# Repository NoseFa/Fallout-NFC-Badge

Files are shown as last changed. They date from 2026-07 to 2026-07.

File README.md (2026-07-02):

# Fallout NFC badge

An NFC badge made for Hack Club Fallout. This project was done on the first full day of Hack Club Fallout as a PCB sprint project. We had around like 7-8h from start to finish. The badge was made to fit the holders / landyards given to us at the event. The badge includes an nfc tag and a whitescreen with a QR code to the fallout home page and a code to my github profile on the back side. I will probably program the nfc tag to forward to the photo site so I can quickly give people access to it. This was also one of my first KiCad projects with PCBA components so it's pretty bare bones and simple. 

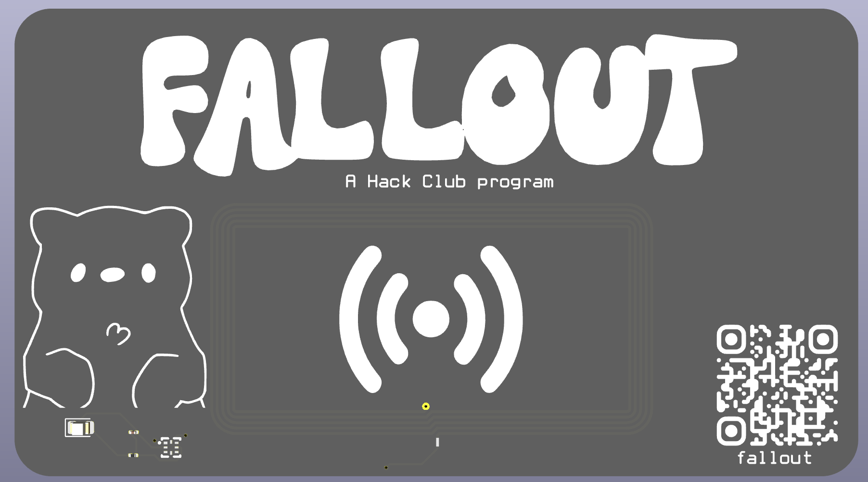
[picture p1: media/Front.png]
Front side


Front side with the NFC tag area, Fallout logo, soup (Fallout's mascot) and a QR code to the Fallout page.

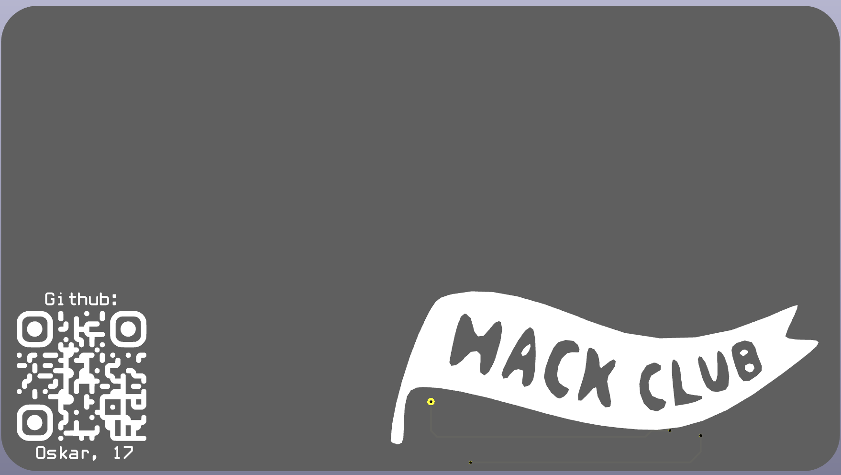
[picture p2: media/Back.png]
Back side


Back side with the Hack Club flag and QR code to my GitHub

## The PCB files

I made this project in KiCad and got it manufactured by JLCPCB as a PCBA. When ordering keep in mind that the antenna might be listed as a part but it doesn't need to be placed so when it gives an error for the antenna not having a part mapped to it in the BOM thats normal. You can find the manufacturing files in [kicad/jlcpcb/production_files](./jlcpcb/production_files/). It includes the gerbers and the BOM.

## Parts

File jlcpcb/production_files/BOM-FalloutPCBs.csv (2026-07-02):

Comment | Designator | Footprint | LCSC | Quantity
NT3H2111W0FHKH | U1 | XQFN-8_L1.6-W1.6-P0.50-BL_NT3H2111W0FHKH | C710403 | 1
Antenna_Loop | AE1 | 25X48MM_NFC |  | 1
LED | D1 | LED_0805_2012Metric |  | 1
R | R1 | R_0201_0603Metric |  | 1
C | C1 | C_0201_0603Metric |  | 1

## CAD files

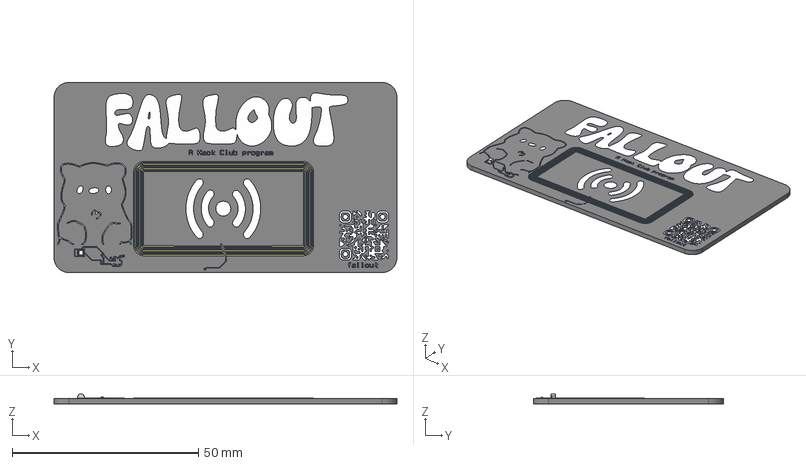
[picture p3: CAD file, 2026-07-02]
Fallout.step
92.0 x 51.0 x 2.77 mm
LED_0805_2012Metric
R_0201_0603Metric
C_0201_0603Metric
FalloutPCBs_copper
FalloutPCBs_via
FalloutPCBs_silkscreen x 2
FalloutPCBs_PCB

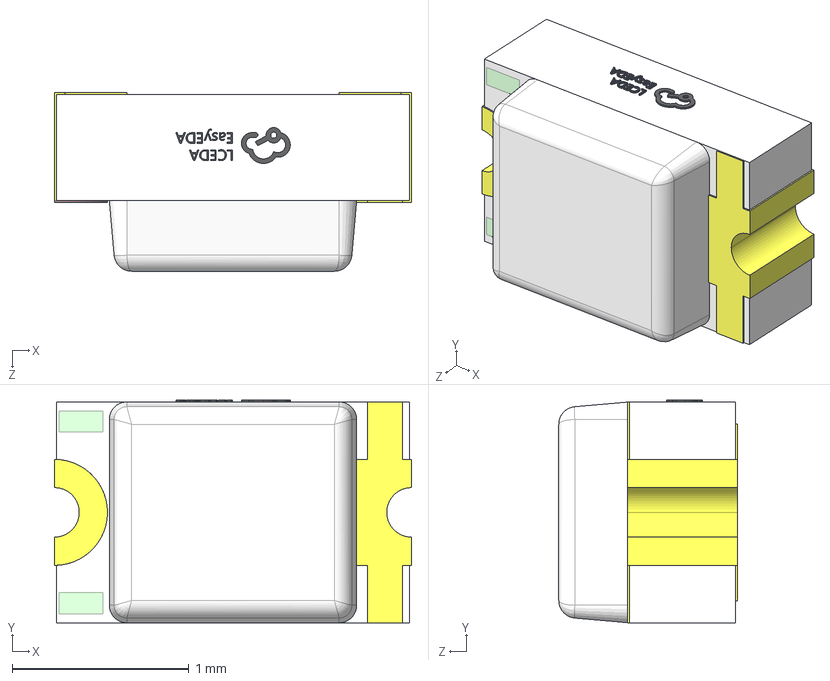
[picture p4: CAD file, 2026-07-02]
symbols/3dshapes/LED0805-RD.step
2.02 x 1.26 x 1.01 mm

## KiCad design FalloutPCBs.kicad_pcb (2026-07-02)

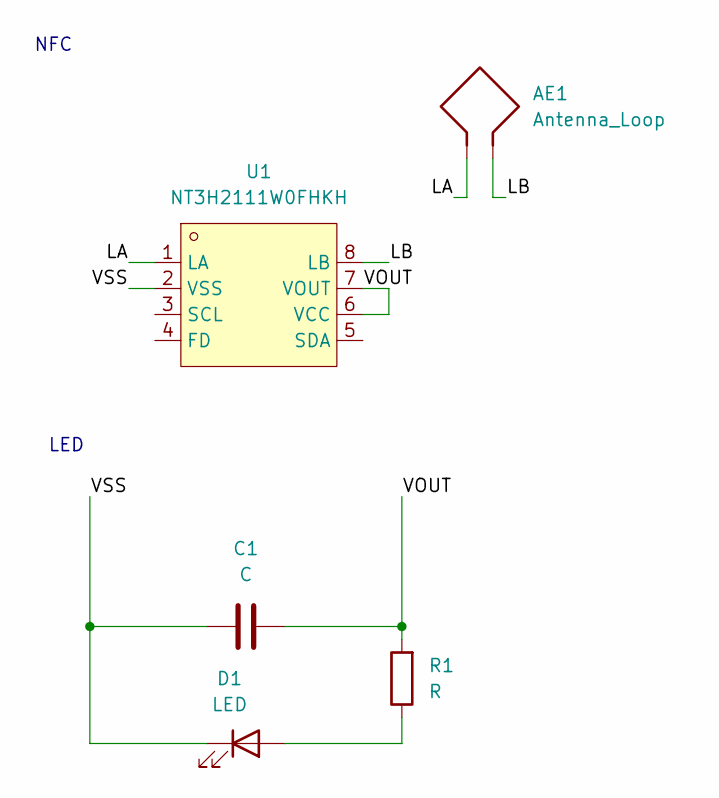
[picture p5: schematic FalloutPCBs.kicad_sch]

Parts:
AE1: Antenna_Loop; 25X48MM_NFC
C1: C; C_0201_0603Metric
D1: LED; LED_0805_2012Metric
R1: R; R_0201_0603Metric
U1: NT3H2111W0FHKH; XQFN-8_L1.6-W1.6-P0.50-BL_NT3H2111W0FHKH; LCSC Part C710403

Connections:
/LA: AE1.1, U1.1 (LA)
/LB: AE1.2, U1.8 (LB)
/VOUT: C1.2, R1.2, U1.6 (VCC), U1.7 (VOUT)
/VSS: C1.1, D1.1 (K), U1.2 (VSS)
unnamed: D1.2 (A), R1.1

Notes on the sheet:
NFC
LED

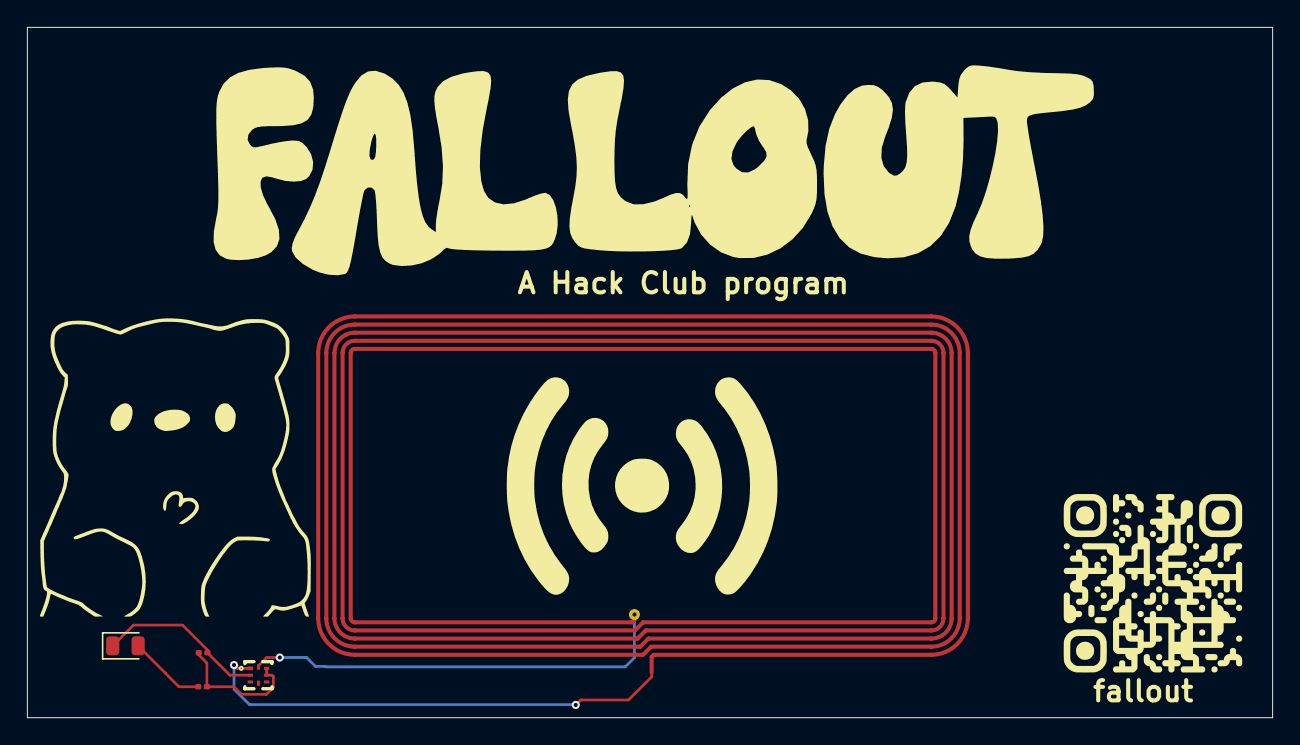
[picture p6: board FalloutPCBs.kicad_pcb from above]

Board: 2 copper layers, 92.0 x 51.0 mm, 5 parts (0 on the bottom side), 5 nets.
